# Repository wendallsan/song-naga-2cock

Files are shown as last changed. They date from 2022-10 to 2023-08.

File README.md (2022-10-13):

# Two-Headed Cockatrice  
### Double Deluxe Voltage Controlled Envelope Generator for Eurorack
Panel Concept Design
Panel Concept Design  

## Features  
- Dual ADSR Envelopes with Gate and Trigger inputs and Voltage Control over each stage.  CV inputs for these controls are shared between both Envelopes with attenuverters for each for independently adjusting the resonse to incoming CV signals.  
- Envelope 2 includes a Voltage Controlled Gate Delay, and is triggered with Envelope 1 when nothing is plugged into its Gate or Trigger inputs.  
- Individual signal outputs for each Envelope and a Mix section, which outputs a mixed signal of both envelopes.  
- LED indicators of the output signals.  
- Fire button to manully trigger the Envelopes

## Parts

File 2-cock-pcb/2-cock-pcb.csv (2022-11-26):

Source: | C:\Users\danst\Documents\Rockstar\Modular\designs\KiCad\development\2-cock\2-cock-pcb\2-cock-pcb.kicad_sch
Date: | 10/31/2022 6:00:15 PM
Tool: | Eeschema (6.0.6)
Generator: | C:\Program Files\KiCad\6.0\bin\scripting\plugins/bom_csv_grouped_by_value_with_fp.py
Component Count: | 118
Ref | Qnty | Value | Cmp name | Footprint | Description | Vendor
C1, C4, C12, C14, C15, C17, C18, C19, | 8 | 10nF | C | Capacitor_SMD:C_0805_2012Metric | Unpolarized capacitor
C2, | 1 | 330nF | C_Small | Capacitor_SMD:C_0805_2012Metric | Unpolarized capacitor, small symbol
C3, C7, C8, C9, C10, C11, C13, C16, | 8 | 100nF | C | Capacitor_SMD:C_0805_2012Metric | Unpolarized capacitor
C5, C6, | 2 | 10uF | C_Polarized_US | Capacitor_SMD:C_0805_2012Metric | Polarized capacitor, US symbol
D1, D2, | 2 | D_Schottky | D_Schottky | Diode_SMD:D_SOD-123 | Schottky diode
D3, D4, D5, | 3 | LED | LED | LED_THT:LED_D5.0mm | Light emitting diode
FB1, FB2, FB3, | 3 | FerriteBead | FerriteBead | Inductor_SMD:L_0805_2012Metric | Ferrite bead
J1, | 1 | EURO_PWR_2x5 | EURO_PWR_2x5 | Connector_IDC:IDC-Header_2x05_P2.54mm_Vertical
J2, | 1 | Delay CV In | AudioJack2_SwitchT | Connector_Audio:Jack_3.5mm_QingPu_WQP-PJ398SM_Vertical_CircularHoles | Audio Jack, 2 Poles (Mono / TS), Switched T Pole (Normalling)
J3, | 1 | Gate 1 | AudioJack2_SwitchT | Connector_Audio:Jack_3.5mm_QingPu_WQP-PJ398SM_Vertical_CircularHoles | Audio Jack, 2 Poles (Mono / TS), Switched T Pole (Normalling)
J4, | 1 | Attack CV In | AudioJack2_SwitchT | Connector_Audio:Jack_3.5mm_QingPu_WQP-PJ398SM_Vertical_CircularHoles | Audio Jack, 2 Poles (Mono / TS), Switched T Pole (Normalling)
J5, | 1 | Decay CV In | AudioJack2_SwitchT | Connector_Audio:Jack_3.5mm_QingPu_WQP-PJ398SM_Vertical_CircularHoles | Audio Jack, 2 Poles (Mono / TS), Switched T Pole (Normalling)
J6, | 1 | Trigger 1 | AudioJack2_SwitchT | Connector_Audio:Jack_3.5mm_QingPu_WQP-PJ398SM_Vertical_CircularHoles | Audio Jack, 2 Poles (Mono / TS), Switched T Pole (Normalling)
J7, | 1 | Sustain CV In | AudioJack2_SwitchT | Connector_Audio:Jack_3.5mm_QingPu_WQP-PJ398SM_Vertical_CircularHoles | Audio Jack, 2 Poles (Mono / TS), Switched T Pole (Normalling)
J8, | 1 | Release CV In | AudioJack2_SwitchT | Connector_Audio:Jack_3.5mm_QingPu_WQP-PJ398SM_Vertical_CircularHoles | Audio Jack, 2 Poles (Mono / TS), Switched T Pole (Normalling)
J9, | 1 | Gate 2 | AudioJack2_SwitchT | Connector_Audio:Jack_3.5mm_QingPu_WQP-PJ398SM_Vertical_CircularHoles | Audio Jack, 2 Poles (Mono / TS), Switched T Pole (Normalling)
J10, | 1 | Trigger 2 | AudioJack2_SwitchT | Connector_Audio:Jack_3.5mm_QingPu_WQP-PJ398SM_Vertical_CircularHoles | Audio Jack, 2 Poles (Mono / TS), Switched T Pole (Normalling)
J11, | 1 | Out 1 | AudioJack2_SwitchT | Connector_Audio:Jack_3.5mm_QingPu_WQP-PJ398SM_Vertical_CircularHoles | Audio Jack, 2 Poles (Mono / TS), Switched T Pole (Normalling)
J12, | 1 | Out 2 | AudioJack2_SwitchT | Connector_Audio:Jack_3.5mm_QingPu_WQP-PJ398SM_Vertical_CircularHoles | Audio Jack, 2 Poles (Mono / TS), Switched T Pole (Normalling)
J13, | 1 | Mix Out | AudioJack2_SwitchT | Connector_Audio:Jack_3.5mm_QingPu_WQP-PJ398SM_Vertical_CircularHoles | Audio Jack, 2 Poles (Mono / TS), Switched T Pole (Normalling)
J14, | 1 | Inv Out | AudioJack2_SwitchT | Connector_Audio:Jack_3.5mm_QingPu_WQP-PJ398SM_Vertical_CircularHoles | Audio Jack, 2 Poles (Mono / TS), Switched T Pole (Normalling)
Q1, Q2, Q3, Q4, Q5, Q6, Q7, | 7 | MMBT3904 | MMBT3904 | Package_TO_SOT_SMD:SOT-23 | 0.2A Ic, 40V Vce, Small Signal NPN Transistor, SOT-23
R1, R4, R10, R17, R22, R25, R28, R30, R37, R41, R42, R43, | 12 | 1k | R | Resistor_SMD:R_0805_2012Metric | Resistor
R2, R15, R21, R38, R39, R40, | 6 | 10k | R | Resistor_SMD:R_0805_2012Metric | Resistor
R3, R5, R7, R9, R11, R13, R14, R18, R23, R26, R29, R31, R32, R33, R35, R36, | 16 | 100k | R | Resistor_SMD:R_0805_2012Metric | Resistor
R6, R12, R20, R24, | 4 | 1M | R | Resistor_SMD:R_0805_2012Metric | Resistor
R8, | 1 | R | R | Resistor_SMD:R_0805_2012Metric | Resistor
R16, | 1 | 200k | R | Resistor_SMD:R_0805_2012Metric | Resistor
R19, | 1 | 27k | R | Resistor_SMD:R_0805_2012Metric | Resistor
R27, R34, | 2 | 50k | R | Resistor_SMD:R_0805_2012Metric | Resistor
RV1, RV2, RV3, RV4, RV5, RV6, RV7, RV8, RV9, RV10, RV11, RV12, RV13, RV14, RV15, RV16, RV17, RV18, | 18 | 100k | R_Potentiometer | Potentiometer_THT:Potentiometer_Alpha_RD901F-40-00D_Single_Vertical | Potentiometer
RV19, | 1 | B100k | R_Potentiometer | Potentiometer_THT:Potentiometer_Alpha_RD901F-40-00D_Single_Vertical | Potentiometer
U1, | 1 | Daisy_Seed | Daisy_Seed | daisy-seed:Daisy_Seed
U2, | 1 | LM7805_TO220 | MC78M05_TO252 | Package_TO_SOT_SMD:TO-252-2 | Positive 500mA 35V Linear Regulator, Fixed Output 5V, TO-252 (D-PAK)
U3, | 1 | TL074 | TL074 | Package_SO:SOIC-14_3.9x8.7mm_P1.27mm | Quad Low-Noise JFET-Input Operational Amplifiers, DIP-14/SOIC-14
U4, | 1 | LM4040DBZ-10 | LM4040DBZ-10 | Package_TO_SOT_SMD:SOT-23 | 10.00V Precision Micropower Shunt Voltage Reference, SOT-23
U5, U7, U8, | 3 | CD4051B | CD4051B | Package_SO:SOIC-16_3.9x9.9mm_P1.27mm | CMOS single 8-channel analog multiplexer demultiplexer, TSSOP-16/DIP-16/SOIC-16
U6, | 1 | MCP6001-OT | MCP6001-OT | Package_TO_SOT_SMD:SOT-23-5_HandSoldering | 1MHz, Low-Power Op Amp, SOT-23-5

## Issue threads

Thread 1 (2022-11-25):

v0.1: Daisy Seed is not available via USB when plugged into PCB

wendallsan, 2022-11-25:
Behavior:

When the Daisy Seed is plugged into the PCB, it is not available to USB.  The program appears to run, and the Daisy Seed appears to run when powered only by Eurorack power.

per @Nick on Daisy Seed Discord:

the onboard USB chip could be getting starved if one of the 3V3 output pins is shorted.

I reviewed the 3V3_A pin: connects to all 18 of the ADC-connected pots and the MCP6001.  There is about 5.5k resistance between 3V3_A and ground (not sure if this is a short or not).

per @squarewolf on Daisy Seed Discord:

hmm, that's odd... I did a quick search on github and found this: https://github.com/electro-smith/Hardware/blob/master/reference/daisy_seed/Datasheet.md#pin-38---3v3-digital It says "Maximum 500mA total combined with MCU/RAM." for the digital 3V3 pin and "Maximum 150mA combined with onboard-AK4556 and Analog section of MCU." for the Analog 3V3 pin. Not sure what the CMU/RAM and the AK4556 and Analog section consume, but at least it's a ballpark...

TODO: look at the 3V3_D pin also and see if it is shorted.
TODO: measure the current of these pins to see if they exceed 500mV.

wendallsan, 2022-11-28:
Per @Corvus Prudens on the Daisy Seed Discord:

5.5k is totally normal. It can often look more like a few hundred ohms depending on the circuit.
The schematic doesn't look wrong in any way.

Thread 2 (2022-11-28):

change C15 value from 10nF to 1nF

wendallsan, 2022-11-28:
Per @Corvus Prudens on the Daisy Seed Discord:

I'd be careful with the muxed CVs: the cutoff on the op amp circuit is around 600 Hz, which means your sampling period for each signal needs to be more like 100Hz or less. You'll get crosstalk between the signals if you switch between them too fast.

I'd take the capacitor (C15) from 10 nF down to 1 if you want to sample the inputs at something like 1kHz.

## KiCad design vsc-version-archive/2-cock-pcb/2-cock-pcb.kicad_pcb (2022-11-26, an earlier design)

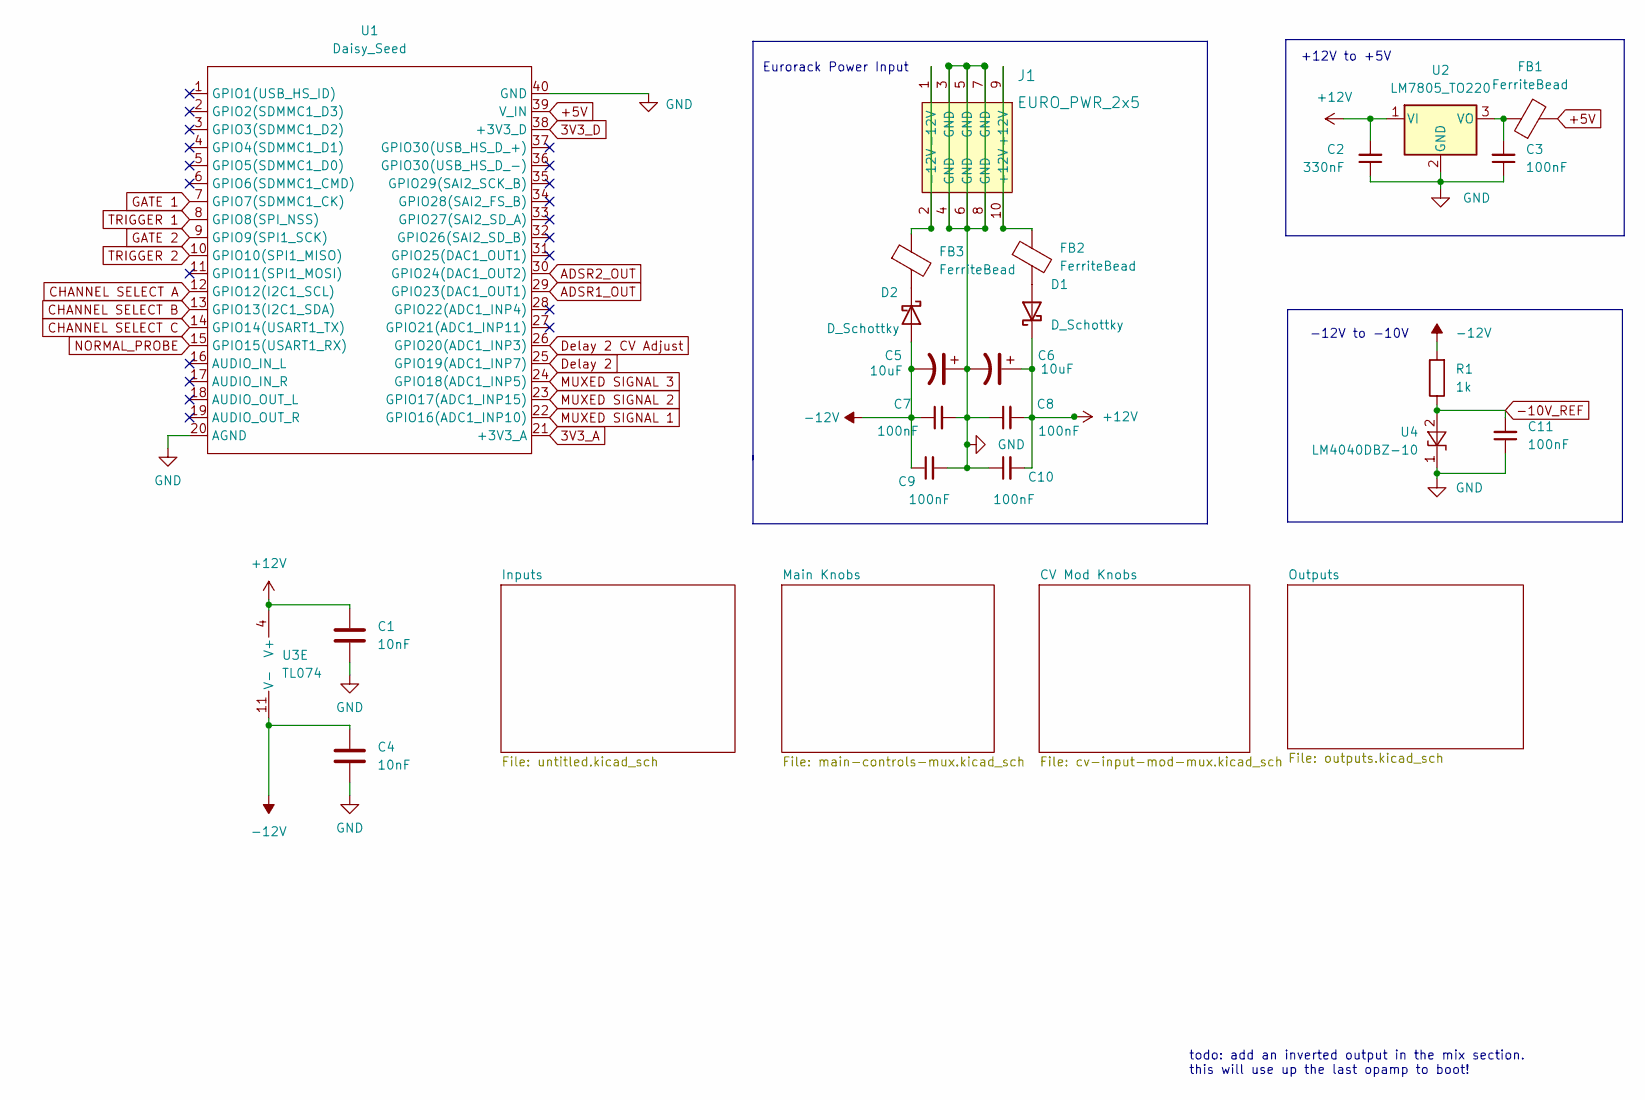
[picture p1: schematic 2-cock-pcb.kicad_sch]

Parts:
C1, C4: 10nF; C_0805_2012Metric
C2: 330nF; C_0805_2012Metric
C3, C7, C8, C9, C10, C11: 100nF; C_0805_2012Metric
C5, C6: 10uF; C_0805_2012Metric
D1, D2: D_Schottky; D_SOD-123
FB1, FB2, FB3: FerriteBead; L_0805_2012Metric
J1: EURO_PWR_2x5; IDC-Header_2x05_P2.54mm_Vertical
R1: 1k; R_0805_2012Metric
U1: Daisy_Seed
U2: LM7805_TO220; TO-252-2
U3: TL074; SOIC-14_3.9x8.7mm_P1.27mm
U4: LM4040DBZ-10; SOT-23

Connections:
3V3_A: U1.21 (+3V3_A); also elsewhere on the board
3V3_D: U1.38 (+3V3_D); also elsewhere on the board
+5V: FB1.2, U1.39 (V_IN)
+12V: C1.1, C2.2, C6.1, C8.2, C10.2, D1.1 (K), U2.1 (VI), U3.4 (V+); also elsewhere on the board
-10V_REF: C11.2, R1.1, U4.2 (A); also elsewhere on the board
-12V: C4.1, C5.2, C7.1, C9.1, D2.2 (A), R1.2, U3.11 (V-); also elsewhere on the board
ADSR1_OUT: U1.29 (GPIO23(DAC1_OUT1)); also elsewhere on the board
ADSR2_OUT: U1.30 (GPIO24(DAC1_OUT2)); also elsewhere on the board
CHANNEL SELECT A: U1.12 (GPIO12(I2C1_SCL)); also elsewhere on the board
CHANNEL SELECT B: U1.13 (GPIO13(I2C1_SDA)); also elsewhere on the board
CHANNEL SELECT C: U1.14 (GPIO14(USART1_TX)); also elsewhere on the board
Delay 2: U1.25 (GPIO19(ADC1_INP7)); also elsewhere on the board
Delay 2 CV Adjust: U1.26 (GPIO20(ADC1_INP3)); also elsewhere on the board
GATE 1: U1.7 (GPIO7(SDMMC1_CK)); also elsewhere on the board
GATE 2: U1.9 (GPIO9(SPI1_SCK)); also elsewhere on the board
GND: C1.2, C2.1, C3.1, C4.2, C5.1, C6.2, C7.2, C8.1, C9.2, C10.1, C11.1, J1.3 (GND), J1.4 (GND), J1.5 (GND), J1.6 (GND), J1.7 (GND), J1.8 (GND), U1.20 (AGND), U1.40 (GND), U2.2 (GND), U4.1 (K); also elsewhere on the board
MUXED SIGNAL 1: U1.22 (GPIO16(ADC1_INP10)); also elsewhere on the board
MUXED SIGNAL 2: U1.23 (GPIO17(ADC1_INP15)); also elsewhere on the board
MUXED SIGNAL 3: U1.24 (GPIO18(ADC1_INP5)); also elsewhere on the board
NORMAL_PROBE: U1.15 (GPIO15(USART1_RX)); also elsewhere on the board
unnamed: C3.2, FB1.1, U2.3 (VO)
unnamed: D1.2 (A), FB2.2
unnamed: D2.1 (K), FB3.2
unnamed: FB2.1, J1.9 (+12V), J1.10 (+12V)
unnamed: FB3.1, J1.1 (-12V), J1.2 (-12V)
TRIGGER 1: U1.8 (GPIO8(SPI_NSS)); also elsewhere on the board
TRIGGER 2: U1.10 (GPIO10(SPI1_MISO)); also elsewhere on the board

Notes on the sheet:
todo: add an inverted output in the mix section. this will use up the last opamp to boot!
-12V to -10V
Eurorack Power Input
+12V to +5V

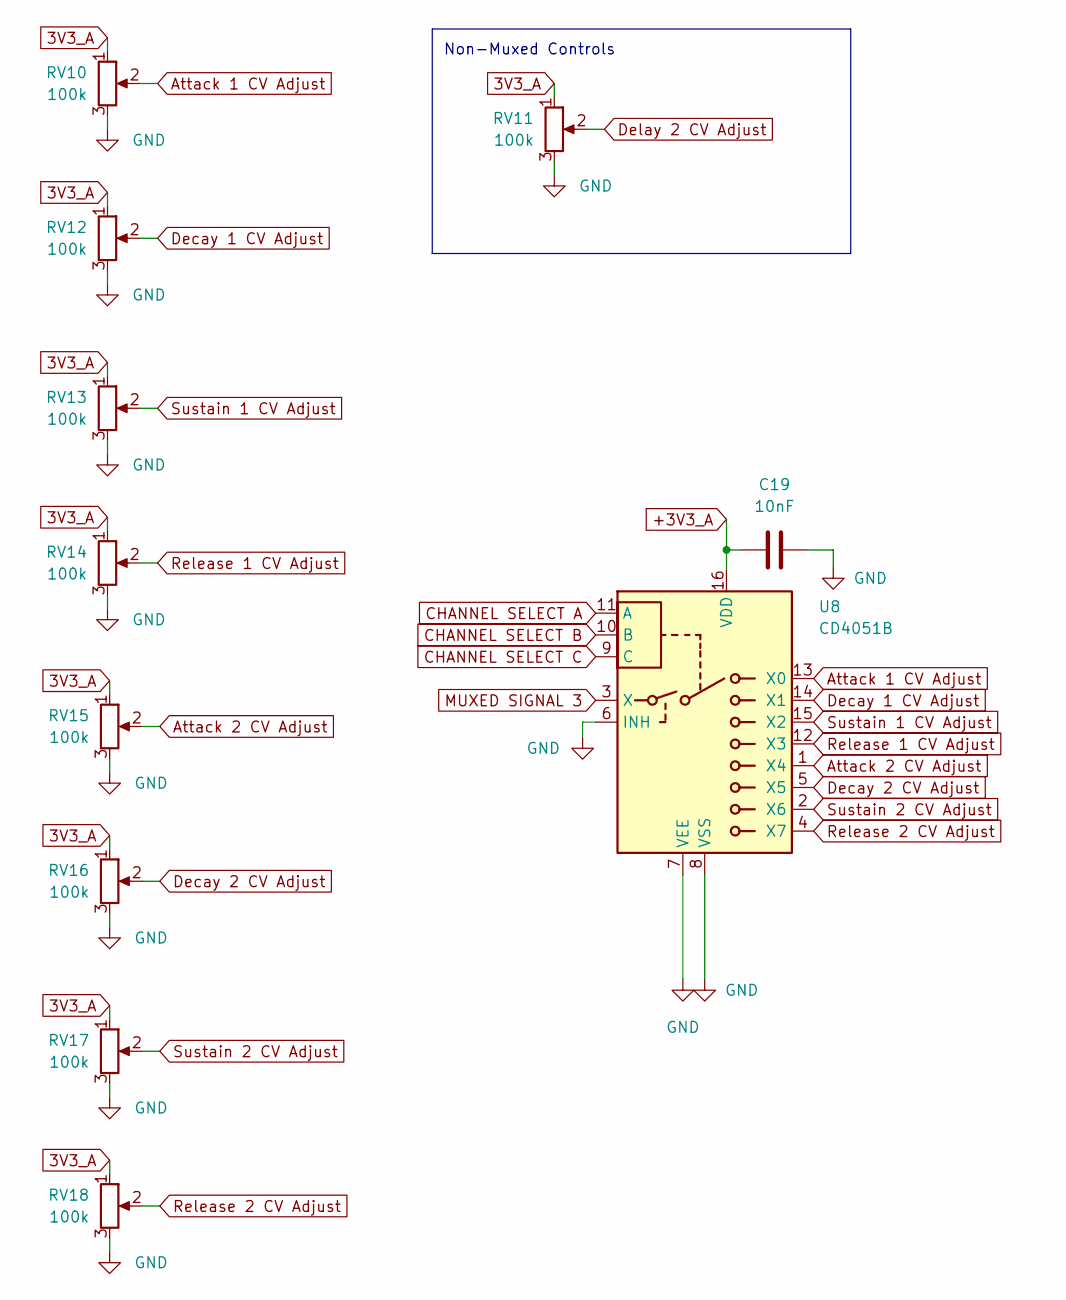
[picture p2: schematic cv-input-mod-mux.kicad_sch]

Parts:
C19: 10nF; C_0805_2012Metric
RV10, RV11, RV12, RV13, RV14, RV15, RV16, RV17, RV18: 100k; Potentiometer_Alpha_RD901F-40-00D_Single_Vertical
U8: CD4051B; SOIC-16_3.9x9.9mm_P1.27mm

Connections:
3V3_A: RV10.1, RV11.1, RV12.1, RV13.1, RV14.1, RV15.1, RV16.1, RV17.1, RV18.1; also elsewhere on the board
+3V3_A: C19.1, U8.16 (VDD); also elsewhere on the board
Attack 1 CV Adjust: RV10.2, U8.13 (X0)
Attack 2 CV Adjust: RV15.2, U8.1 (X4)
CHANNEL SELECT A: U8.11 (A); also elsewhere on the board
CHANNEL SELECT B: U8.10 (B); also elsewhere on the board
CHANNEL SELECT C: U8.9 (C); also elsewhere on the board
Decay 1 CV Adjust: RV12.2, U8.14 (X1)
Decay 2 CV Adjust: RV16.2, U8.5 (X5)
Delay 2 CV Adjust: RV11.2; also elsewhere on the board
GND: C19.2, RV10.3, RV11.3, RV12.3, RV13.3, RV14.3, RV15.3, RV16.3, RV17.3, RV18.3, U8.6 (INH), U8.7 (VEE), U8.8 (VSS); also elsewhere on the board
MUXED SIGNAL 3: U8.3 (X); also elsewhere on the board
Release 1 CV Adjust: RV14.2, U8.12 (X3)
Release 2 CV Adjust: RV18.2, U8.4 (X7)
Sustain 1 CV Adjust: RV13.2, U8.15 (X2)
Sustain 2 CV Adjust: RV17.2, U8.2 (X6)

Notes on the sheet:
Non-Muxed Controls

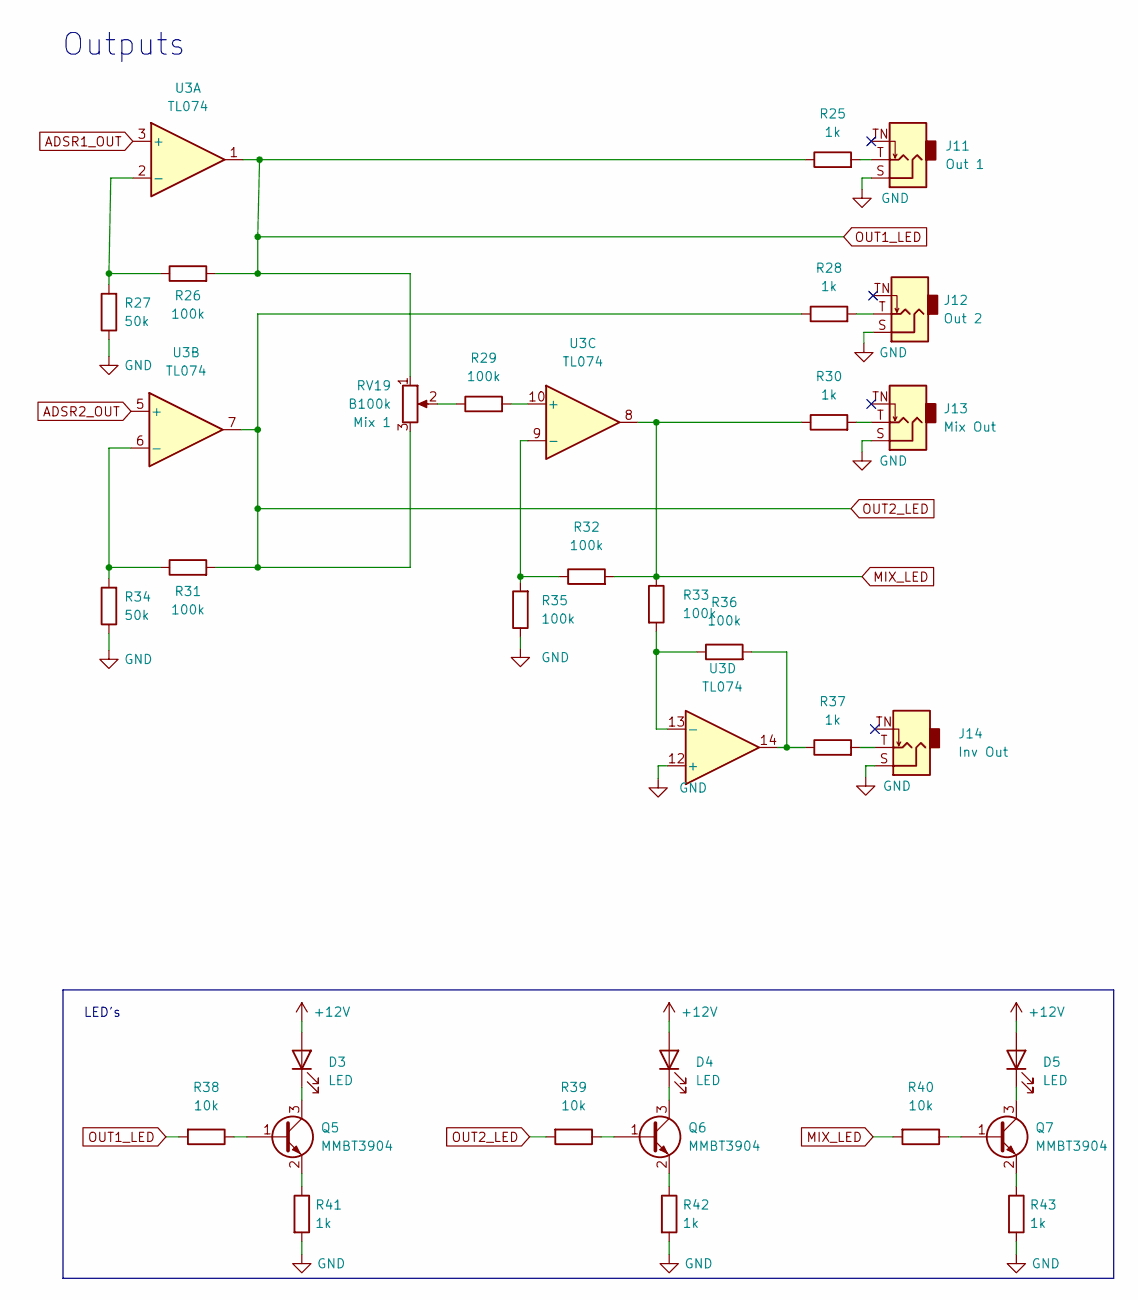
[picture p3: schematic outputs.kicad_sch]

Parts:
D3, D4, D5: LED; LED_D5.0mm
J11: Out 1; Jack_3.5mm_QingPu_WQP-PJ398SM_Vertical_CircularHoles
J12: Out 2; Jack_3.5mm_QingPu_WQP-PJ398SM_Vertical_CircularHoles
J13: Mix Out; Jack_3.5mm_QingPu_WQP-PJ398SM_Vertical_CircularHoles
J14: Inv Out; Jack_3.5mm_QingPu_WQP-PJ398SM_Vertical_CircularHoles
Q5, Q6, Q7: MMBT3904; SOT-23
R25, R28, R30, R37, R41, R42, R43: 1k; R_0805_2012Metric
R26, R29, R31, R32, R33, R35, R36: 100k; R_0805_2012Metric
R27, R34: 50k; R_0805_2012Metric
R38, R39, R40: 10k; R_0805_2012Metric
RV19: B100k; Potentiometer_Alpha_RD901F-40-00D_Single_Vertical
U3: TL074; SOIC-14_3.9x8.7mm_P1.27mm

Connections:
+12V: D3.2 (A), D4.2 (A), D5.2 (A); also elsewhere on the board
ADSR1_OUT: U3.3 (+); also elsewhere on the board
ADSR2_OUT: U3.5 (+); also elsewhere on the board
GND: J11.S, J12.S, J13.S, J14.S, R27.1, R34.1, R35.1, R41.2, R42.2, R43.2, U3.12 (+); also elsewhere on the board
MIX_LED: R30.1, R32.2, R33.1, R40.2, U3.8
unnamed: D3.1 (K), Q5.3 (C)
unnamed: D4.1 (K), Q6.3 (C)
unnamed: D5.1 (K), Q7.3 (C)
unnamed: J11.T, R25.2
unnamed: J12.T, R28.2
unnamed: J13.T, R30.2
unnamed: J14.T, R37.2
unnamed: Q5.1 (B), R38.1
unnamed: Q5.2 (E), R41.1
unnamed: Q6.1 (B), R39.1
unnamed: Q6.2 (E), R42.1
unnamed: Q7.1 (B), R40.1
unnamed: Q7.2 (E), R43.1
unnamed: R26.1, R27.2, U3.2 (-)
unnamed: R29.1, RV19.2
unnamed: R29.2, U3.10 (+)
unnamed: R31.1, R34.2, U3.6 (-)
unnamed: R32.1, R35.2, U3.9 (-)
unnamed: R33.2, R36.1, U3.13 (-)
unnamed: R36.2, R37.1, U3.14
OUT1_LED: R25.1, R26.2, R38.2, RV19.1, U3.1
OUT2_LED: R28.1, R31.2, R39.2, RV19.3, U3.7

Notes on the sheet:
Outputs
LED's

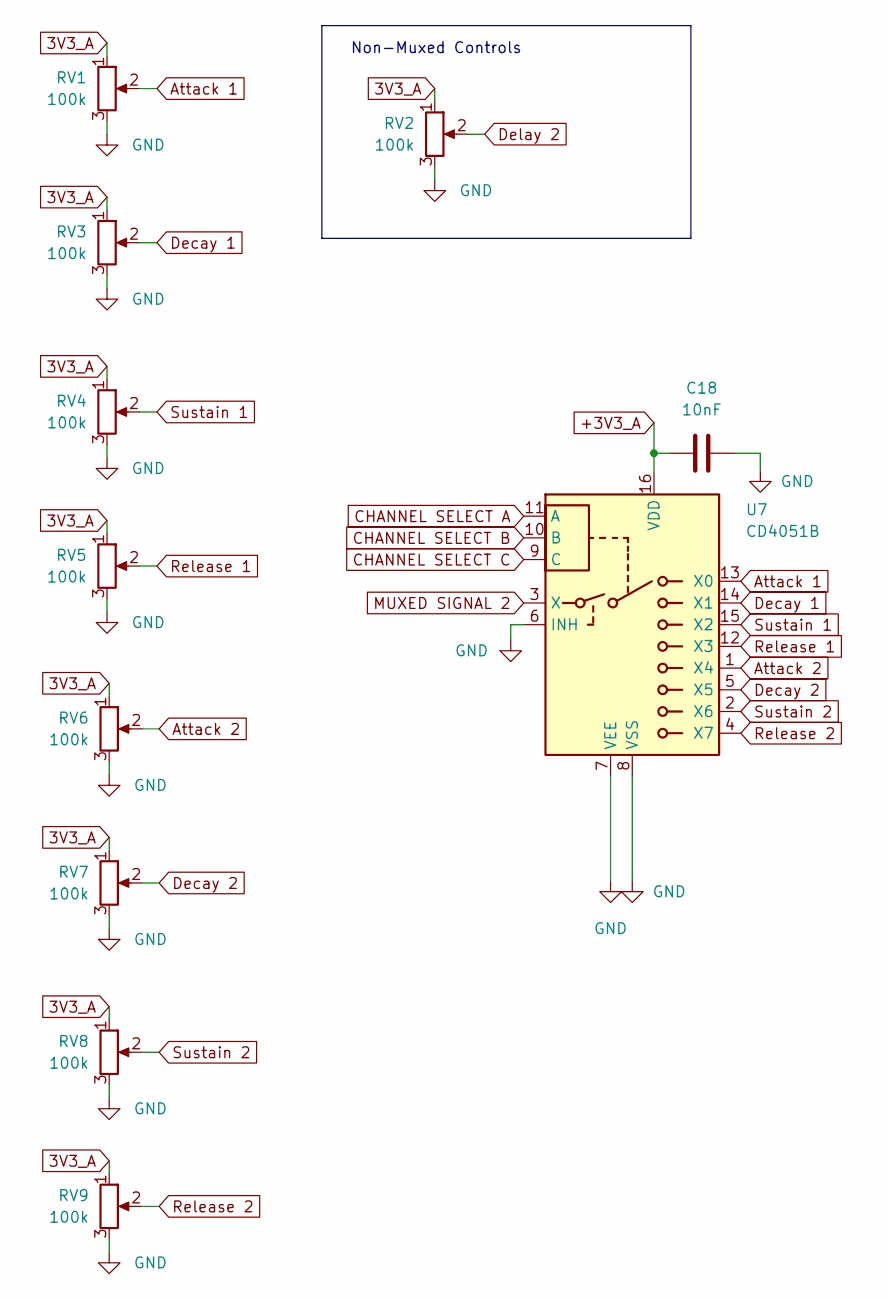
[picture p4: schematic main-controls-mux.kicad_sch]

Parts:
C18: 10nF; C_0805_2012Metric
RV1, RV2, RV3, RV4, RV5, RV6, RV7, RV8, RV9: 100k; Potentiometer_Alpha_RD901F-40-00D_Single_Vertical
U7: CD4051B; SOIC-16_3.9x9.9mm_P1.27mm

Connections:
3V3_A: RV1.1, RV2.1, RV3.1, RV4.1, RV5.1, RV6.1, RV7.1, RV8.1, RV9.1; also elsewhere on the board
+3V3_A: C18.1, U7.16 (VDD); also elsewhere on the board
Attack 1: RV1.2, U7.13 (X0)
Attack 2: RV6.2, U7.1 (X4)
CHANNEL SELECT A: U7.11 (A); also elsewhere on the board
CHANNEL SELECT B: U7.10 (B); also elsewhere on the board
CHANNEL SELECT C: U7.9 (C); also elsewhere on the board
Decay 1: RV3.2, U7.14 (X1)
Decay 2: RV7.2, U7.5 (X5)
Delay 2: RV2.2; also elsewhere on the board
GND: C18.2, RV1.3, RV2.3, RV3.3, RV4.3, RV5.3, RV6.3, RV7.3, RV8.3, RV9.3, U7.6 (INH), U7.7 (VEE), U7.8 (VSS); also elsewhere on the board
MUXED SIGNAL 2: U7.3 (X); also elsewhere on the board
Release 1: RV5.2, U7.12 (X3)
Release 2: RV9.2, U7.4 (X7)
Sustain 1: RV4.2, U7.15 (X2)
Sustain 2: RV8.2, U7.2 (X6)

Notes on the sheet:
Non-Muxed Controls

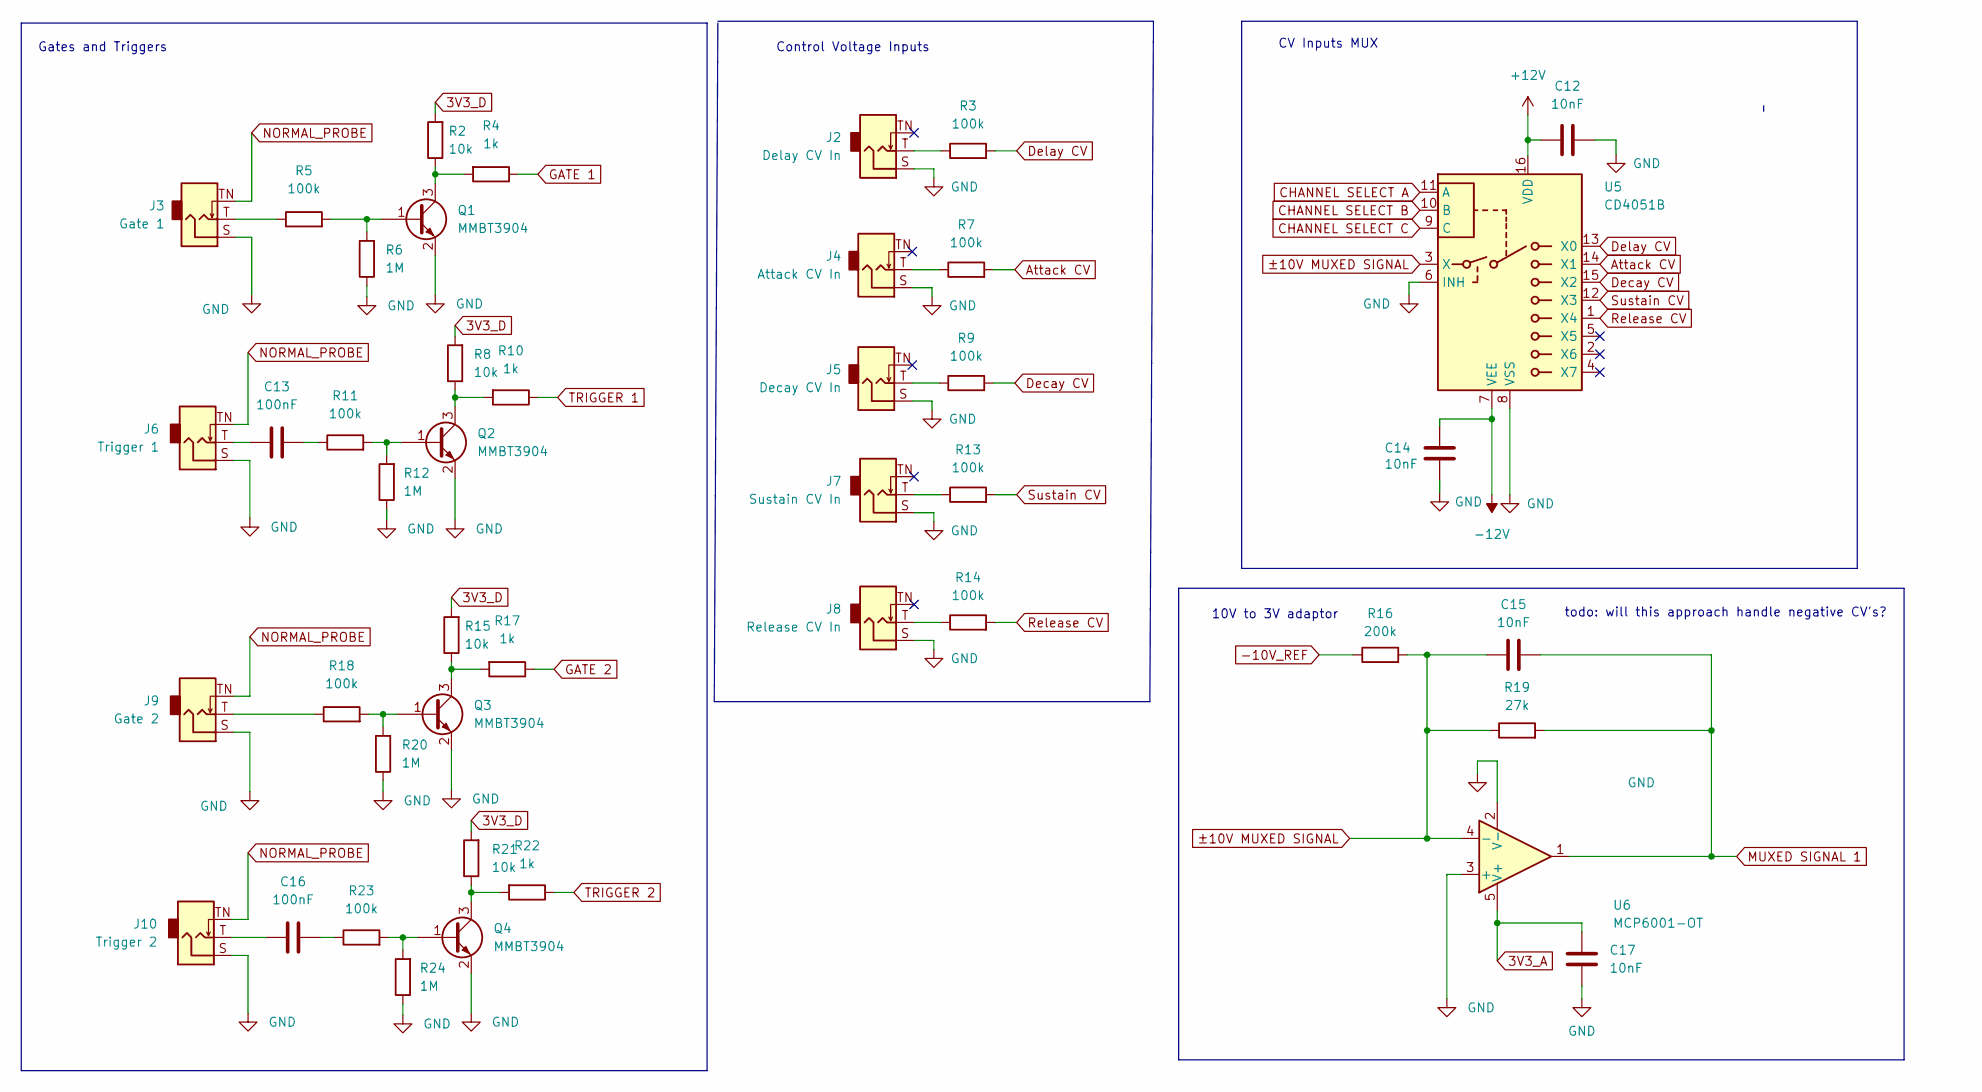
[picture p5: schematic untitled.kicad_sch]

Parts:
C12, C14, C15, C17: 10nF; C_0805_2012Metric
C13, C16: 100nF; C_0805_2012Metric
J2: Delay CV In; Jack_3.5mm_QingPu_WQP-PJ398SM_Vertical_CircularHoles
J3: Gate 1; Jack_3.5mm_QingPu_WQP-PJ398SM_Vertical_CircularHoles
J4: Attack CV In; Jack_3.5mm_QingPu_WQP-PJ398SM_Vertical_CircularHoles
J5: Decay CV In; Jack_3.5mm_QingPu_WQP-PJ398SM_Vertical_CircularHoles
J6: Trigger 1; Jack_3.5mm_QingPu_WQP-PJ398SM_Vertical_CircularHoles
J7: Sustain CV In; Jack_3.5mm_QingPu_WQP-PJ398SM_Vertical_CircularHoles
J8: Release CV In; Jack_3.5mm_QingPu_WQP-PJ398SM_Vertical_CircularHoles
J9: Gate 2; Jack_3.5mm_QingPu_WQP-PJ398SM_Vertical_CircularHoles
J10: Trigger 2; Jack_3.5mm_QingPu_WQP-PJ398SM_Vertical_CircularHoles
Q1, Q2, Q3, Q4: MMBT3904; SOT-23
R2, R8, R15, R21: 10k; R_0805_2012Metric
R3, R5, R7, R9, R11, R13, R14, R18, R23: 100k; R_0805_2012Metric
R4, R10, R17, R22: 1k; R_0805_2012Metric
R6, R12, R20, R24: 1M; R_0805_2012Metric
R16: 200k; R_0805_2012Metric
R19: 27k; R_0805_2012Metric
U5: CD4051B; SOIC-16_3.9x9.9mm_P1.27mm
U6: MCP6001-OT; SOT-23-5_HandSoldering

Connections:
3V3_A: C17.1, U6.5 (V+); also elsewhere on the board
3V3_D: R2.2, R8.2, R15.2, R21.2; also elsewhere on the board
+12V: C12.1, U5.16 (VDD); also elsewhere on the board
-10V_REF: R16.1; also elsewhere on the board
-12V: C14.1, U5.7 (VEE); also elsewhere on the board
Attack CV: R7.2, U5.14 (X1)
CHANNEL SELECT A: U5.11 (A); also elsewhere on the board
CHANNEL SELECT B: U5.10 (B); also elsewhere on the board
CHANNEL SELECT C: U5.9 (C); also elsewhere on the board
Decay CV: R9.2, U5.15 (X2)
Delay CV: R3.2, U5.13 (X0)
GATE 1: R4.1; also elsewhere on the board
GATE 2: R17.1; also elsewhere on the board
GND: C12.2, C14.2, C17.2, J2.S, J3.S, J4.S, J5.S, J6.S, J7.S, J8.S, J9.S, J10.S, Q1.2 (E), Q2.2 (E), Q3.2 (E), Q4.2 (E), R6.1, R12.1, R20.1, R24.1, U5.6 (INH), U5.8 (VSS), U6.2 (V-), U6.3 (+); also elsewhere on the board
MUXED SIGNAL 1: C15.2, R19.2, U6.1; also elsewhere on the board
NORMAL_PROBE: J3.TN, J6.TN, J9.TN, J10.TN; also elsewhere on the board
unnamed: C13.1, J6.T
unnamed: C13.2, R11.1
unnamed: C16.1, J10.T
unnamed: C16.2, R23.1
unnamed: J2.T, R3.1
unnamed: J3.T, R5.1
unnamed: J4.T, R7.1
unnamed: J5.T, R9.1
unnamed: J7.T, R13.1
unnamed: J8.T, R14.1
unnamed: J9.T, R18.1
unnamed: Q1.1 (B), R5.2, R6.2
unnamed: Q1.3 (C), R2.1, R4.2
unnamed: Q2.1 (B), R11.2, R12.2
unnamed: Q2.3 (C), R8.1, R10.2
unnamed: Q3.1 (B), R18.2, R20.2
unnamed: Q3.3 (C), R15.1, R17.2
unnamed: Q4.1 (B), R23.2, R24.2
unnamed: Q4.3 (C), R21.1, R22.2
Release CV: R14.2, U5.1 (X4)
Sustain CV: R13.2, U5.12 (X3)
TRIGGER 1: R10.1; also elsewhere on the board
TRIGGER 2: R22.1; also elsewhere on the board
±10V MUXED SIGNAL: C15.1, R16.2, R19.1, U5.3 (X), U6.4 (-)

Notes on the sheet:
CV Inputs MUX
Gates and Triggers
Control Voltage Inputs
10V to 3V adaptor
todo: will this approach handle negative CV's?

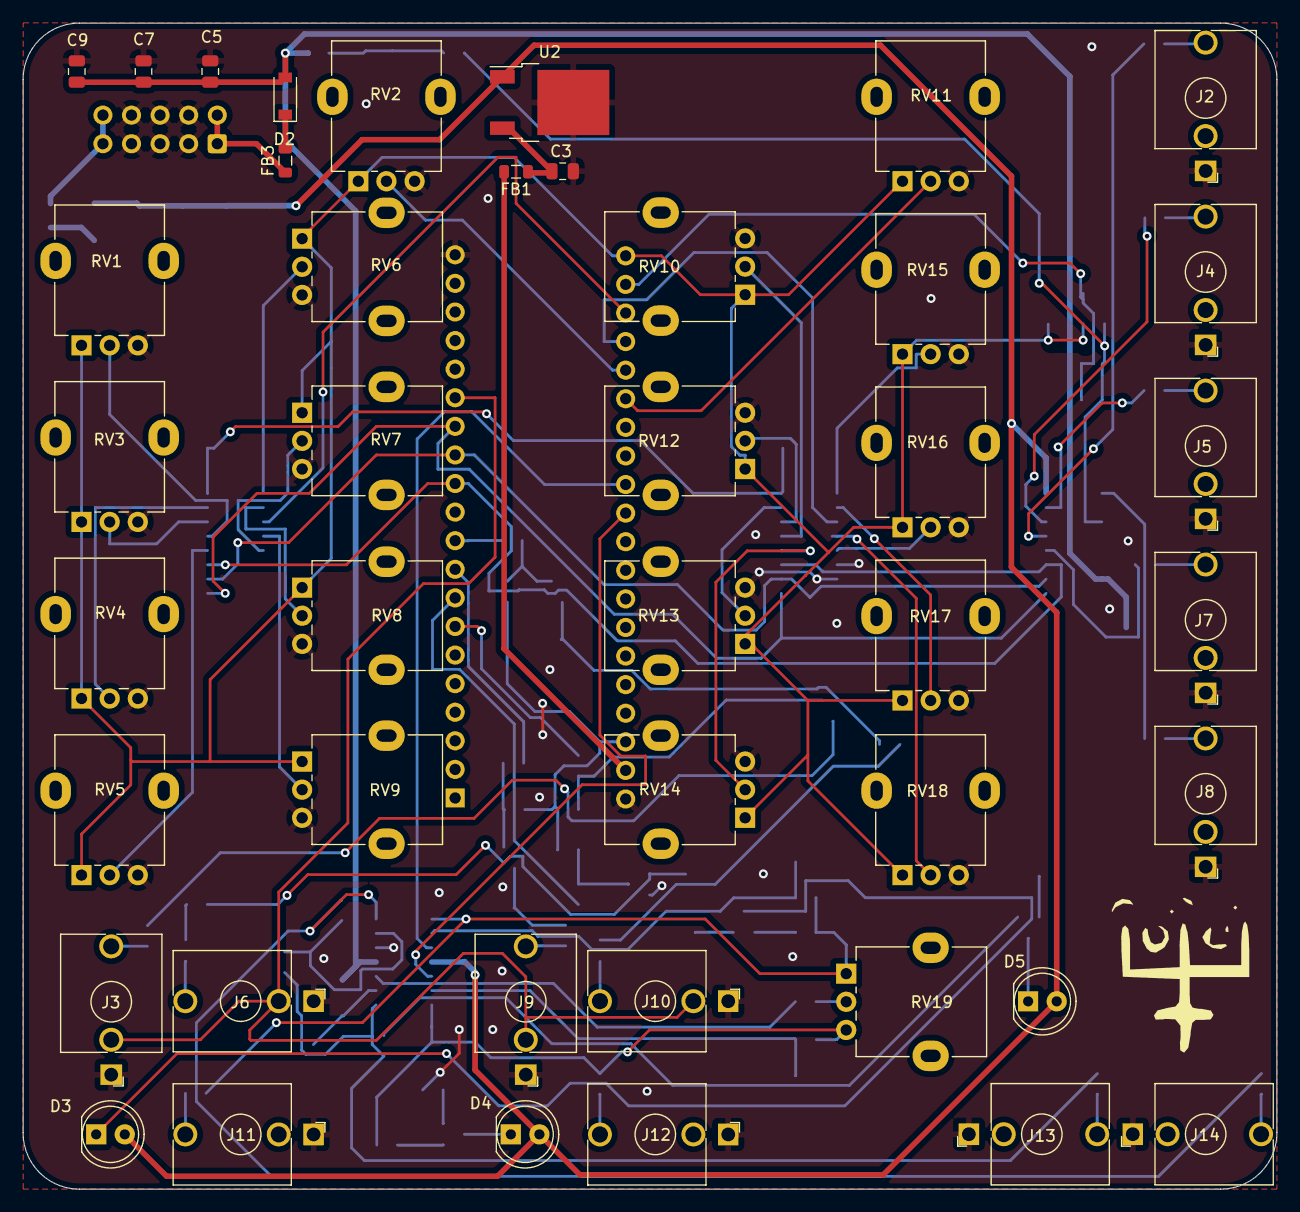
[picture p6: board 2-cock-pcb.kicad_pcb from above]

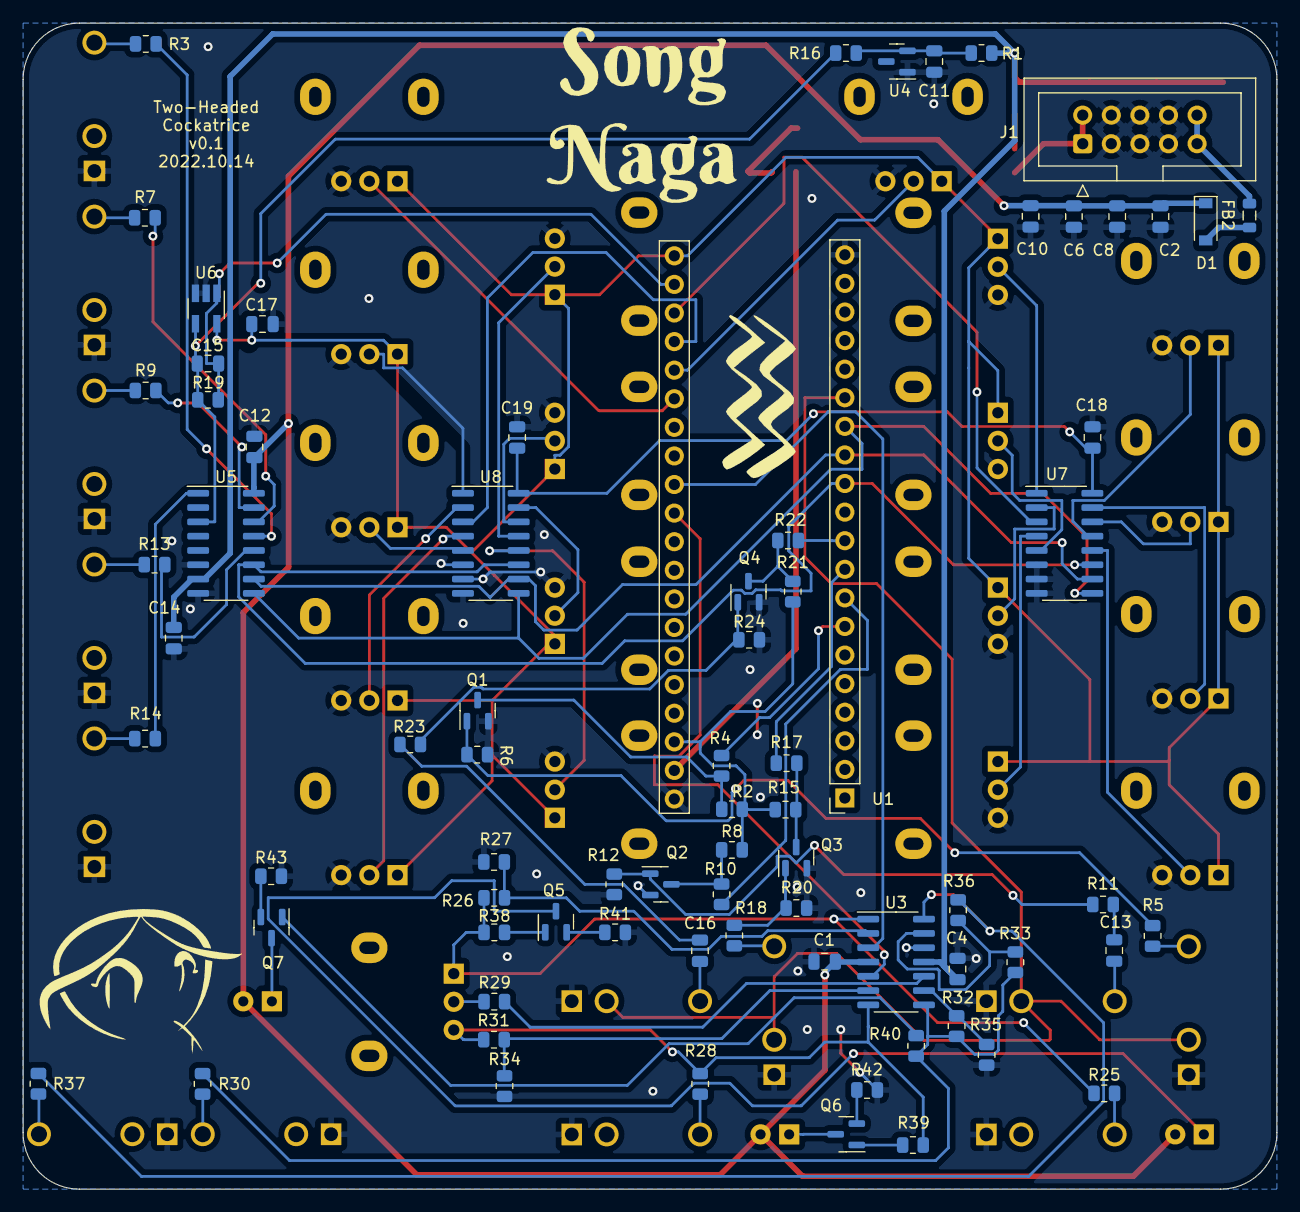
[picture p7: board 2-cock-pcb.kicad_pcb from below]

Board: 2 copper layers, 111.4 x 103.6 mm, 122 parts (78 on the bottom side), 92 nets.

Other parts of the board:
G1, G2, G3, G4: LOGO

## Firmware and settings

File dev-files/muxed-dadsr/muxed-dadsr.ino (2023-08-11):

#include <Wire.h>
#include <Adafruit_MCP4725.h>

#define ADC_MAX 1023
#define ENV_MAX 4095
#define ENV_MIN 0
#define ATTACK_THRESHOLD 4000

#define MUX_CHANNELS 8
#define MUX_SELECT_1_PIN 11  // GP11 = PIN 15
#define MUX_SELECT_2_PIN 12  // GP12 = PIN 16
#define MUX_SELECT_3_PIN 13  // GP13 = PIN 17
#define TRIGGER_PIN_1 14     // GP15 = PIN 19
#define GATE_PIN_1 16        // GP16 = PIN 21
#define LED_PIN 25           // GP25 = LED

enum testMuxChannels { DELAY1, ATTACK1, DECAY1, SUSTAIN1, RELEASE1, MEOW1, MEOW2, MEOW3 };

Adafruit_MCP4725 dac1;
bool isGate1 = false,
  isTrigger1 = false,
  lastTrigger1 = false,
  envelopeIsActive1 = false,
  isDecayState1 = false,
  isRetrigger1 = false;
int muxValues1[MUX_CHANNELS] = { 0, 0, 0, 0, 0, 0, 0, 0 },
  targetValue1 = 0,
  muxCounter = 0,
  attackCV = 0,
  decayCV = 0,
  sustainCV = 0,
  releaseCV = 0,
  debugCount = 0;
float currentPole1 = 0.7,  // INITIALIZE POLE LOCATIONS
  currentEnvelopeValue1 = 0.0;
unsigned long delay1StartTime = 0;
double attackPole1 = 0.9,  // INITIALIZE ATACK, DECAY AND RELEASE POLES
  decayPole1 = 0.9,
  releasePole1 = 0.95;
double calcPole(int poleValue) {
  // return sqrt(0.999 * cos( double(ADC_MAX - poleValue) / 795.0));
  return sqrt(0.999 * cos(double(ADC_MAX - poleValue) / 4000.0));  // this seems to work better.
}
float delta(double targetPole, int targetValue1, float currentValue) {
  return (1.0 - targetPole) * targetValue1 + targetPole * currentValue;
}
void setMuxSelectPins() {
  digitalWrite(MUX_SELECT_1_PIN, bitRead(muxCounter, 0));
  digitalWrite(MUX_SELECT_2_PIN, bitRead(muxCounter, 1));
  digitalWrite(MUX_SELECT_3_PIN, bitRead(muxCounter, 2));
}
void setEnvPoles1() {
  switch (muxCounter) {
    case ATTACK1:
      attackPole1 = calcPole(muxValues1[ATTACK1]);
      break;
    case DECAY1:
      decayPole1 = calcPole(muxValues1[DECAY1]);
      break;
    case RELEASE1:
      releasePole1 = calcPole(muxValues1[RELEASE1]);
      break;
  }
}
void handleMuxes() {
  setMuxSelectPins();
  muxValues1[muxCounter] = ADC_MAX - analogRead(A0);
  setEnvPoles1();
  muxCounter++;
  if (muxCounter >= MUX_CHANNELS) muxCounter = 0;
}
void handleGatesAndTriggers() {
  isGate1 = digitalRead(GATE_PIN_1);
  isTrigger1 = !digitalRead(TRIGGER_PIN_1) && !lastTrigger1;
  isRetrigger1 = isGate1 && isTrigger1;
  if (!isRetrigger1 && !isGate1 && isTrigger1) isGate1 = true;
}
bool handleDelay1() {
  if (muxValues1[DELAY1] > 10) {
    if (delay1StartTime == 0) {
      delay1StartTime = millis();
      return true;
    } else if( millis() < delay1StartTime + (unsigned long) ( muxValues1[DELAY1] * 2 ) ) return true; // UP TO 2 SECONDS OF DELAY!
  }
  return false;
}
void updateEnvelope1() {
  if (isGate1) {  // IF GATE IS HAPPENING...
    if (!handleDelay1()) {  // IF WE'RE NOT DOING A DELAY...
      if (!envelopeIsActive1) { // IF envelopeIsActive IS FALSE, WE'VE DETECTED THE START OF A NEW ENVELOPE!
        isDecayState1 = false;
        targetValue1 = ENV_MAX;
        currentPole1 = attackPole1;
        envelopeIsActive1 = true;
      }
      if (isRetrigger1) {  // IF WE'RE RETRIGGERING...
        envelopeIsActive1 = true;
        isDecayState1 = false;
        targetValue1 = ENV_MAX;
        currentPole1 = attackPole1;
        // ELSE IF WE ARE AT THE END OF THE ATTACK PHASE... (AKA IF NOT DECAY AND AT ATTACK THRESHOLD YET AND TARGET VALUE IS ENV_MAX)
      } else if (!isDecayState1 && (currentEnvelopeValue1 > ATTACK_THRESHOLD) && (targetValue1 == ENV_MAX)) {
        isDecayState1 = true;
        targetValue1 = muxValues1[SUSTAIN1] * 4;
        currentPole1 = decayPole1;
      }
    }
  } else {  // ELSE THE GATE IS NOT ON, WE ARE IN THE RELEASE PHASE
    targetValue1 = ENV_MIN;
    currentPole1 = releasePole1;
    envelopeIsActive1 = false;
    isDecayState1 = true;
    delay1StartTime = 0;
  }
  currentEnvelopeValue1 = delta(currentPole1, targetValue1, currentEnvelopeValue1);
  dac1.setVoltage(round(currentEnvelopeValue1), false);
  lastTrigger1 = isTrigger1;
}
void setup() {
  Serial.begin(9600);
  analogReadResolution(10);  // SET ANALOG READ TO 10 BITS (VALUE RANGE 0 - 1023)
  dac1.begin(0x62);
  pinMode(GATE_PIN_1, INPUT_PULLDOWN);
  pinMode(TRIGGER_PIN_1, INPUT_PULLDOWN);
  pinMode(MUX_SELECT_1_PIN, OUTPUT);
  pinMode(MUX_SELECT_2_PIN, OUTPUT);
  pinMode(MUX_SELECT_3_PIN, OUTPUT);
  pinMode(LED_PIN, OUTPUT);
}
void loop() {
  handleMuxes();
  handleGatesAndTriggers();
  updateEnvelope1();
  debugCount++;
  if( debugCount >= 200 ){    
    Serial.print( "0.0 1.0 " );
    Serial.print(currentEnvelopeValue1/ENV_MAX);
    Serial.print(" ");
    Serial.println( isGate1? "0.8" : "0.2" );
    debugCount = 0;
  }
}

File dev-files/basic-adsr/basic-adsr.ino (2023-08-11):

#include <Wire.h>
#include <Adafruit_MCP4725.h>

#define ADC_MAX 1023
#define DAC_MAX 4095
#define ATTACK_THRESHOLD 4000
#define POLE_DIVISOR 795
#define MUX_CHANNELS 8

enum mainControlsMuxChannels {
  ADSR1_ATTACK,
  ADSR1_DECAY,
  ADSR1_SUSTAIN,
  ADSR1_RELEASE,
  ADSR2_ATTACK,
  ADSR2_DECAY,
  ADSR2_SUSTAIN,
  ADSR2_RELEASE
};


Adafruit_MCP4725 dac;

bool gateIsHigh = false,
     envelopeIsActive = false,
     isDecayState = false;
int muxValues[MUX_CHANNELS] = {0, 0, 0, 0, 0, 0, 0, 0},
  gatePin = 22,
  attackAnalogReadValue = ADC_MAX,  // MANUALLY SET THIS SINCE WE HAVE NO KNOB FOR IT CURRENTLY
  targetValue = 0,
  muxCounter = 0;
float currentPole = 0.7,       // INITIALIZE POLE LOCATION
  currentEnvelopeValue = 0.0;  // INITIALIZE THE ENVELOPE TO 0.0
double attackPole = 0.9,       // INITIALIZE ATACK, DECAY AND RELEASE POLES
  decayPole = 0.9,
       releasePole = 0.95;


int r0 = 0,  //value of select pin at the 4051 (s0)
  r1 = 0,    //value of select pin at the 4051 (s1)
  r2 = 0,    //value of select pin at the 4051 (s2)
  s0 = 2,
    s1 = 3,
    s2 = 4,
    count = 0;  //which y pin we are selecting





int getAttackAnalogReadValue() {
  // return analogRead(A1);
  return muxValues[ADSR1_ATTACK];
}
int getDecayAnalogReadValue() {
  return muxValues[ADSR1_DECAY];
}
int getSustainAnalogReadValue() {
  return muxValues[ADSR1_SUSTAIN];
}
int getReleaseAnalogReadValue() {
  return muxValues[ADSR1_RELEASE];
}
double calculatePole(int poleValue) {
  return sqrt(0.999 * cos((ADC_MAX - poleValue) / POLE_DIVISOR));
}
float differenceEquation(double targetPole, int targetValue, float currentValue) {
  return (1.0 - targetPole) * targetValue + targetPole * currentValue;
}
void handleMux() {
  r0 = bitRead(muxCount, 0);
  r1 = bitRead(muxCount, 1);
  r2 = bitRead(muxCount, 2);

  digitalWrite(s0, r0);
  digitalWrite(s1, r1);
  digitalWrite(s2, r2);
  muxValues[muxCount] = analogRead(A0);
  switch (muxCount) {
    case ADSR1_ATTACK:
      attackPole = calculatePole(getAttackAnalogReadValue());
      break;
    case ADSR1_DECAY:
      decayPole = calculatePole(getDecayAnalogReadValue());
      break; 
    // case ADSR1_SUSTAIN: 
      // NO ACTION IS NEEDED, AS WE READ STRAIGHT FROM THE STORED ARRAY VALUE FOR THIS.
    //  break;
    case ADSR1_RELEASE:
      releasePole = calculatePole(getReleaseAnalogReadValue());
      break;
  }
  muxCount++;
  if (muxCount >= MUX_CHANNELS) muxCount = 0;
}
void setup() {
  analogReadResolution(10);  // SET ANALOG READ TO 10 BITS (VALUE RANGE 0 - 1023)
  dac.begin(0x62);
  pinMode(gatePin, INPUT_PULLDOWN);  // SET UP THE GATE INPUT PIN
  pinMode(s0, OUTPUT);
  pinMode(s1, OUTPUT);
  pinMode(s2, OUTPUT);
}
void loop() {
  handleMux();
  gateIsHigh = digitalRead(gatePin);
  while (gateIsHigh) {
    if (!envelopeIsActive) {
      isDecayState = false;
      targetValue = DAC_MAX;
      currentPole = attackPole;
      envelopeIsActive = true;
    }
    if (!isDecayState && (currentEnvelopeValue > ATTACK_THRESHOLD) && (targetValue == DAC_MAX)) {
      isDecayState = true;
      targetValue = getSustainAnalogReadValue() * 4;
      currentPole = decayPole;
    }
    currentEnvelopeValue = differenceEquation(currentPole, targetValue, currentEnvelopeValue);
    dac.setVoltage(round(currentEnvelopeValue), false);
    gateIsHigh = digitalRead(gatePin);
  }
  if (envelopeIsActive) {
    targetValue = 0;
    currentPole = releasePole;
    envelopeIsActive = false;
  }
  currentEnvelopeValue = differenceEquation(releasePole, targetValue, currentEnvelopeValue);
  dac.setVoltage(round(currentEnvelopeValue), false);
  gateIsHigh = digitalRead(gatePin);
}

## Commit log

2022-08-17 initial commit. Basic working ADSR example with a button trigger.
2022-08-28 2cock.cpp: added mux handling, currently set up to handle adsr1 and adsr2 pots. Added adsr2. Added delaySignal ADC Channel for single input (doesn't fit on the mux). Updated DAC to output 2 channels 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
    [2cock.cpp]
2022-09-02 changed delayline to store the gate signal rather than the ADSR output. This works, except that the gate gets confused when pressing the trigger button more frequently than the gate time. I think we 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
    [2cock.cpp]
2022-09-02 delayline is working! Added check for button release. Set delayTime as a class property so it can be set anywhere. Cleaned up setting delayTime from knob code. General code cleanup.
2022-09-11 Added gate and trigger sockets., which include normal detection on the sockets. Added initTriggersAndGates to set up IO pins and handleTriggersAndGates to handle interactions with those pins. Added n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
2022-10-13 added normalization probe features.
2022-11-26 Incremental commit: updates to 2cock.cpp to make it compatible with v0.1 board and initial testing notes and code. Added KiCAD files for reference.
    [2-cock-pcb-02.dsn, 2-cock-pcb-02.kicad_pcb, 2-cock-pcb-rounded.kicad_pcb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]
2023-08-11 moved prior version's code to vsc-version-archive. added dev-files folder, which contains development files for adruino 2.0 IDE. Most current version as of this commit is muxed-dadsr.
    [2-cock-pcb-02.dsn, 2-cock-pcb-02.kicad_pcb, 2-cock-pcb-rounded.kicad_pcb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]
